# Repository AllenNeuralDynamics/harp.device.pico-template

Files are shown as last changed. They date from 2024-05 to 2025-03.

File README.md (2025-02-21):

# harp.device.pico-template

An RP2040-based Harp hardware/firmware project template.

## Features
* predefined *.gitignore* file to remove extraneous KiCAD (hardware) files.
### Hardware
* Schematic template for a generic Harp Device including:
  * ground-isolated Full Speed USB communication
  * 3.5mm audio jack for Harp-protocol time synchronization
  * RP2040 MCU and required "jellybean" components including:
    * 2MB external flash (Winbond MPN: W25Q16JVUXIQ TR).
  * 2 power supply chain options for power derived from either USB directly or from a DC barrel jack.
* Basic PCBA Layout with size hints for various existing enclosures
  * DC Barrel Jack (2.1 x 5.5mm, positive center)
  * USBC
  * 3.5mm audio jack for Harp synchronization signal
  * Ground lug
### Firmware
* basic "hello-world" project with corresponding file structure
* populated CMakeLists.txt for compliation
* placeholder USB descriptors for Manufacturer and Description fields (in the CMakeLists.txt)
* compilation [instructions](./firmware/README.md)
* harp protocol core library included as a submodule [harp.core.pico](https://github.com/AllenNeuralDynamics/harp.core.pico)

# Using this template
Start by clicking the "Use this Template" button in the upper right corner, or click [here](https://github.com/new?template_name=harp.device.pico-template&template_owner=AllenNeuralDynamics).
## Repository Setup
* If the project has a corresponding Allen Institute SIPE project number, prepend the repository description with: `{SIPE Project Number}:`.
* add the tag `Harp`
* Long-term: remove these instructions!

## Hardware
* Remove all unused hardware folder starter projects.
* 🔧 Design your hardware.
* In the PCBA silkscreen, add:
  * SIPE part number with full hardware semantic version appended in the format: `{SIPE Project Number}-E-{hw major}-{hw minor}-{hw patch}`. Version number fields range from 1-999 and include leading zeros.
  * [QR code](https://www.the-qrcode-generator.com/) linking to the Github repository.

## Firmware
* Update the *Manufacturer* and *Description* USB descriptors in the CMakeLists.txt
* 📝 Write your firmware.

# Github Release Conventions
Releases specify any vetted changes to the hardware or firmware.

Each release specifies:
* semantic versions of changed elements: hardware or firmware.
* SIPE part number (or part numbers if multiple are compatible)

Each hardware release includes:
* STEP file of the PCB (or link to corresponding CAD files) named with the SIPE part number
* schematic (PDF)
* Gerber files (with logos removed) of the PCBA
* Position files for component placement
* Bill-of-Materials for the PCBA

Each hardware release specifies:
* compatible SIPE part number(s)

> [!NOTE]
> SIPE part numbers only encode hardware semantic version major number, so multiple minor/patch hardware releases may point to the same SIPE part number.

> [!NOTE]
> It is possible for a project to have PCBA variants--possibly with very different functionality. In this case, reserve a hardware major version range (>100 suggested) for this variant and treat it as a distinct hardware release (i.e: with all corresponding included hardware files).

Each firmware release specifies:
* firmware semantic version
* compatible hardware (SIPE part number or part number range).

Each firmware release includes:
* compiled binary file (**\*.uf2**) of the firmware.

## Release Title
The release title is specified as follows:

`hw{hw major}.{hw minor}.{hw patch}-fw{fw major}.{fw minor}.{fw patch}`

If the release has firmware-only changes, you can drop the `hw*` section, and vice versa.

> [!NOTE]
> After Oct 2024, hardware major fields on all future releases will be equivalent to the major version number of the SIPE part number. See the [SIPE PCBA part numbering standard](https://alleninstitute.sharepoint.com/:w:/s/Instrumentation/EYsRN8q4jHJDmG5DNf-gaM0Bq418YMXollFxtB9d_NZ6pg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) for more details.

The above field spec enables automation utilities to find the latest firmware version and automatically update compatible hardware. Since releases can include changes to some, but not other fields, unchanged fields are omitted. (i.e: firmware-only changes would be titled `fw{fw major}.{fw minor}.{fw patch}`.)

## Creating a New Release
1. Make a [git tag](https://git-scm.com/book/en/v2/Git-Basics-Tagging) based on the commit in the main branch that you'd like to create the release from. Use the naming convention specified in the [Release Title](#release-title) section.
2. Push the tag to Github.
3. From the repository's corresponding *Release* page, create a new release from the tag you just added. Give it the same title as the tag.
4. If the release includes new _firmware_, compile it locally, and upload a copy of the *.uf2* file as an attachment.
5. If the release includes new _hardware_, upload:
    1. the gerber files (zipped)
    2. the position files
    3. any manufacturing notes (component orientations)
    4. the bill-of-materials
    5. a PDF of the schematic.

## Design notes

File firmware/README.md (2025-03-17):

There are two sets of instructions, one for [Windows](#windows-setup) and one for [Linux](linux-setup).

# Windows Setup

Windows has two sub-options for developing:
* Option A: use Visual Studio Code (easy way)
* Option B: develop with any IDE and compile from the command line.

> [!NOTE]
> For Option B, simply install [Windows Subsystem for Linux](https://learn.microsoft.com/en-us/windows/wsl/install), and then follow the directions in the [Linux](#linux-setup) section of this guide. The rest of this section covers Option A.
  
## Pre-requisites
1. Install [Visual Studio Code](https://code.visualstudio.com/).
2. Install the [Pico Extension for Visual Studio Code](https://marketplace.visualstudio.com/items?itemName=raspberry-pi.raspberry-pi-pico)

## Project Setup
In Visual Studio, click on the Pico icon that appears after installing the Pico Extension. Select _Import Project_ and import the _firmware_ folder of this repository.
Choose the default options.

## Compiling the Firmware
Click the _compile_ button at the corner of the screen. When the compilation finishes, you're ready to [flash the firmware](#flashing-the-firmware).

# Linux Setup

## Pre-requisites

You will need CMake, make, and the gcc-arm-embedded toolchain.

On Linux, install the following:
```bash
sudo apt install cmake python3 build-essential gcc-arm-none-eabi libnewlib-arm-none-eabi libstdc++-arm-none-eabi-newlib
```

### Install Submodules
This project uses the Harp [core.pico](https://github.com/harp-tech/core.pico) library as a submodule.
Install it with:
````
git submodule update --init
````

### Install Pico SDK
This project uses the [Pico SDK](https://github.com/raspberrypi/pico-sdk/tree/master).
The SDK needs to be downloaded and installed to a known folder on your PC.
Note that the PICO SDK also contains submodules (including TinyUSB), so you must ensure that they are also fetched with:
````
git clone git clone git@github.com:raspberrypi/pico-sdk.git
git submodule update --init --recursive
````

### Point to Pico SDK
Optional: define the `PICO_SDK_PATH` environment variable to point to the location where the pico-sdk was downloaded. i.e:
````
PICO_SDK_PATH=/home/username/projects/pico-sdk
````
On Linux, you can define it in your `.bashrc` file.
On Windows, you can define it via System Properties ([tutorial](https://www.computerhope.com/issues/ch000549.htm)).

Confirm that the environment variable is applied to your system by opening a terminal (Powershell on Windows) and
entering (with the `$` sign)
```bash
$PICO_SDK_PATH
```
to confirm that the path was defined correctly.
(Windows may require a restart for the environment variable to take effect.)

## Compiling the Firmware

### With the Visual Studio Code Extension
Using the Pico extension, import the *firmware* folder with the default options.

Click the compile button.

### Without an IDE
From within this folder, create a new folder called *build*, enter it, and invoke cmake with:
````
mkdir build
cd build
cmake ..
````
If you did not define the `PICO_SDK_PATH` as an environment variable, you must pass it in here like so:
````
mkdir build
cd build
cmake -DPICO_SDK_PATH=/path/to/pico-sdk ..
````
After this point, you can invoke the auto-generated Makefile with `make`

## Flashing the Firmware
Press-and-hold the Pico's BOOTSEL button and power it up (i.e: plug it into usb).
At this point you do one of the following:
* drag-and-drop the created **\*.uf2** file into the mass storage device that appears on your pc.
* flash with [picotool](https://github.com/raspberrypi/picotool)

# References
* [YouTube: How to Set Up Visual Studio Code to Program the Pi Pico (Windows)](https://www.youtube.com/watch?v=mUF9xjDtFfY&t=55s)
* [Pico SDK: Unix Command Line](https://github.com/raspberrypi/pico-sdk?tab=readme-ov-file#unix-command-line) Setup

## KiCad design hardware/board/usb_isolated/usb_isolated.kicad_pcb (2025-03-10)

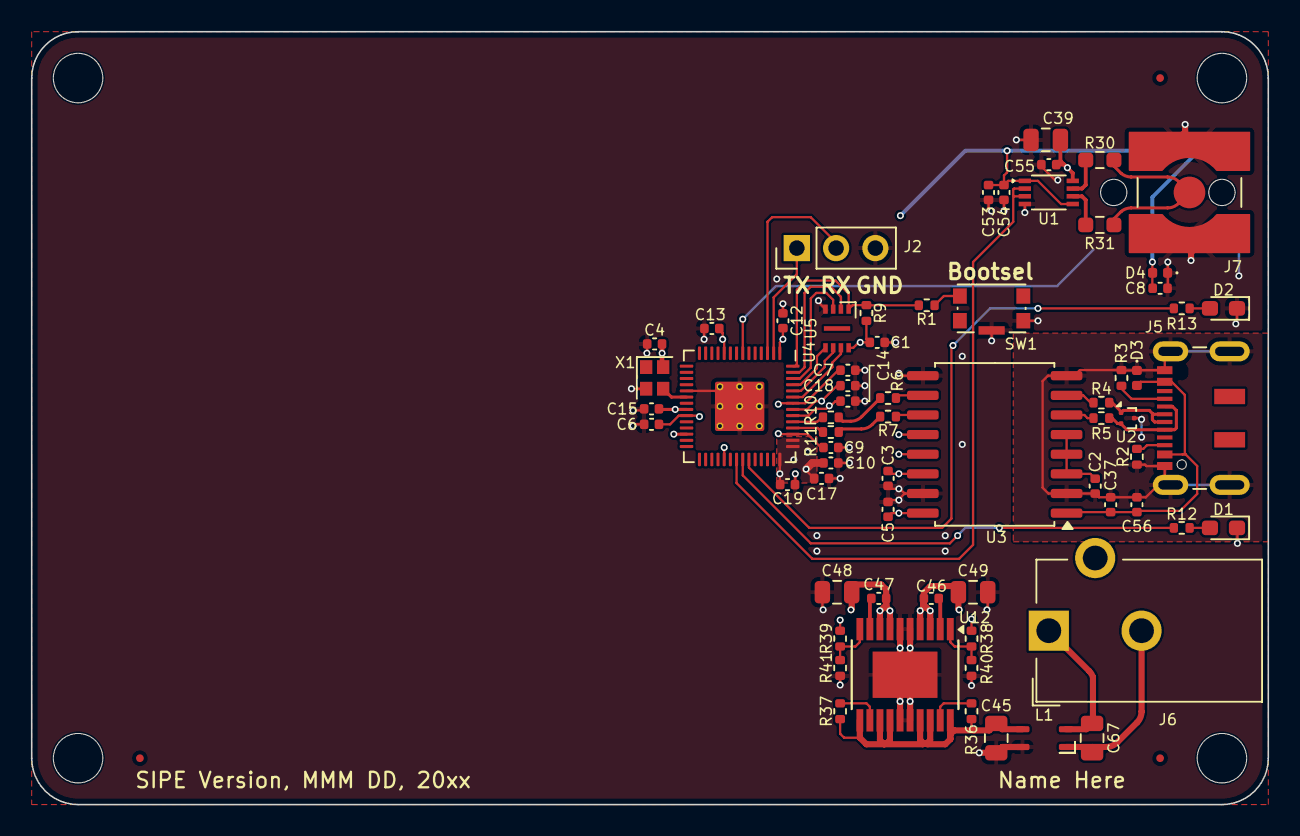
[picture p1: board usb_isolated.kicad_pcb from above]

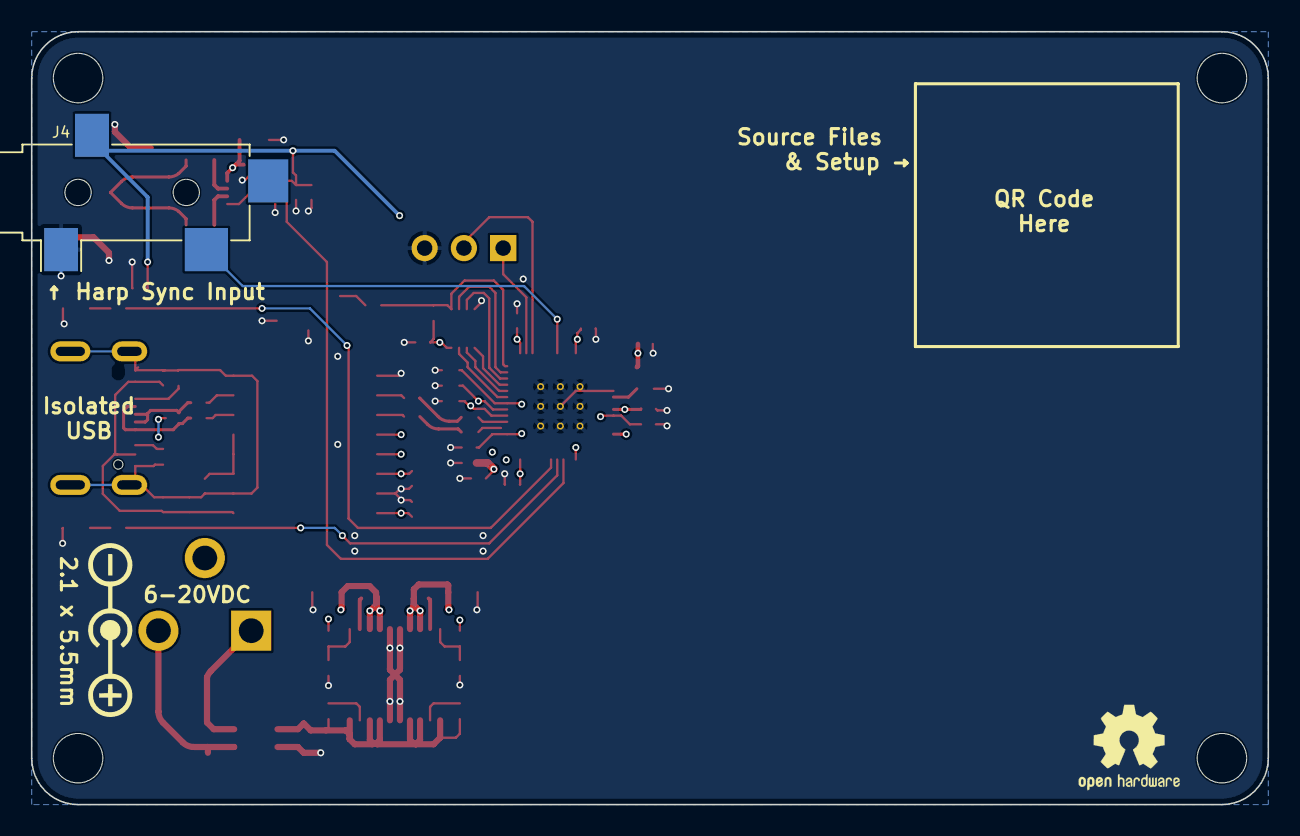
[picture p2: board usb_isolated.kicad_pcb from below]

Board: 4 copper layers, 80.0 x 50.0 mm, 72 parts (3 on the bottom side), 47 nets.

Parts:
C1, C2, C3, C5, C6, C7, C12, C13, C14, C15, C17, C18, C19, C37, C54, C55: 100nF; C_0402_1005Metric
C4, C46, C47: 10nF; C_0402_1005Metric
C8, C9, C10, C53, C56: 1uF; C_0402_1005Metric
C39, C48: 10uF; C_0805_2012Metric
C45, C67: 3.3uF; C_0805_2012Metric
C49: 22uF; C_0805_2012Metric
D1, D2: LED; LED_0603_1608Metric_Pad1.05x0.95mm_HandSolder
D3, D4: D_TVS; D_0402_1005Metric
FID1, FID2, FID3: Fiducial; Fiducial_0.5mm_Mask1mm
G3: LOGO
J2: Conn_01x03_Male; PinHeader_1x03_P2.54mm_Vertical
J4: AudioJack3; Jack_3.5mm_CUI_SJ-3524-SMT_Horizontal
J5: USB_C_Receptacle_USB2.0; USB_C_Receptacle_JAE_DX07S016JA1R1500
J6: Barrel_Jack_Switch; BarrelJack_CUI_PJ-102AH_Horizontal
J7: Conn_Coaxial; SMA_TE_Connectivity_CONSMA002-SMD-G-T_Horizontal
L1: L_Coupled_1423; L_CommonModeChoke_TDKCorporation_1210
R1: 1K; R_0402_1005Metric
R2, R3: 5K1; R_0402_1005Metric
R4, R5, R6, R7: 24; R_0402_1005Metric
R9: 10K; R_0402_1005Metric
R10, R11: 27; R_0402_1005Metric
R12, R13: 680; R_0402_1005Metric
R30, R31: 100; R_0603_1608Metric_Pad0.98x0.95mm_HandSolder
R36, R37: 1M; R_0402_1005Metric
R38: 309K; R_0402_1005Metric
R39: 172K; R_0402_1005Metric
R40, R41: 100K; R_0402_1005Metric
REF1: OSHW-Logo2_7.3x6mm_SilkScreen
SW1: SW_Push_1P1T-SH_NO_Vertical_Wuerth_WS-TASV
U1: 74LVCH2T45DC; VSSOP-8_2.3x2mm_P0.5mm
U2: TPD2EUSB30; Texas_DRT-3
U3: ADUM4160; SOIC-16W_7.5x10.3mm_P1.27mm
U4: RP2040; RP2040-QFN-56
U5: W25Q16JVUXIQ; Winbond-8USON-2x3mm
U12: LT3030; ETSSOP-20-1EP_4.4x6.5mm_P0.65mm_EP3x4.2mm
X1: ECS-TXO-2016; Crystal_SMD_2016-4Pin_2.0x1.6mm

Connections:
+1V1: C6.2, C7.2, C9.1, U4.23 (DVDD), U4.45 (VREG_VOUT), U4.50 (DVDD)
+3.3V: C1.2, C3.2, C4.2, C5.2, C8.1, C10.1, C12.2, C13.2, C14.2, C15.2, C17.2, C18.2, C19.2, C47.1, C48.1, C53.1, C54.2, D4.2 (A2), J4.R, R9.2, R39.1, U1.1 (VCCA), U1.5 (DIR), U3.12 (PIN), U3.13 (SPD), U3.14 (VDD2), U3.16 (VBUS2), U4.1 (IOVDD), U4.10 (IOVDD), U4.22 (IOVDD), U4.26 (RUN), U4.33 (IOVDD), U4.42 (IOVDD), U4.43 (ADC_AVDD), U4.44 (VREG_IN), U4.48 (USB_VDD), U4.49 (IOVDD), U5.8 (VCC), U12.7 (OUT2), U12.8 (OUT2), X1.4 (VDD)
+5V: C39.1, C46.1, C49.1, C55.2, R38.1, U1.8 (VCCB), U12.3 (OUT1), U12.4 (OUT1)
+12V: C67.1, J6.1, L1.2
/Harp Core RP2040 + Isolated USB/D+: J5.A6 (D+), J5.B6 (D+), R4.1, U2.1 (D+)
/Harp Core RP2040 + Isolated USB/D-: J5.A7 (D-), J5.B7 (D-), R5.1, U2.2 (D-)
/Harp Core RP2040 + Isolated USB/DD+: R6.2, R10.2
/Harp Core RP2040 + Isolated USB/DD-: R7.2, R11.2
/Harp Core RP2040 + Isolated USB/HARP_CLK_SYNC: J4.T, U4.7 (GPIO5)
/Harp Core RP2040 + Isolated USB/QSPI_CLK: U4.52 (QSPI_SCLK), U5.6 (CLK)
/Harp Core RP2040 + Isolated USB/QSPI_CS: R1.2, R9.1, U4.56 (QSPI_SS), U5.1 (~CS)
/Harp Core RP2040 + Isolated USB/QSPI_D0: U4.53 (QSPI_SD0), U5.5 (DI(IO0))
/Harp Core RP2040 + Isolated USB/QSPI_D1: U4.55 (QSPI_SD1), U5.2 (DO(IO1))
/Harp Core RP2040 + Isolated USB/QSPI_D2: U4.54 (QSPI_SD2), U5.3 (IO2)
/Harp Core RP2040 + Isolated USB/QSPI_D3: U4.51 (QSPI_SD3), U5.7 (IO3)
/Harp Core RP2040 + Isolated USB/TTL_OUT: U1.2 (1A), U1.3 (2A), U4.35 (GPIO23)
/Harp Core RP2040 + Isolated USB/UART0_RXD: J2.2, U4.3 (GPIO1)
/Harp Core RP2040 + Isolated USB/UART0_TXD: J2.1, U4.2 (GPIO0)
/Harp Core RP2040 + Isolated USB/USB_Boot: R1.1, SW1.2
/Harp Core RP2040 + Isolated USB/VDD1: C2.2, U3.3 (VDD1), U3.4 (PDEN), U3.5 (SPU)
GND: C1.1, C3.1, C4.1, C5.1, C6.1, C7.1, C8.2, C9.2, C10.2, C12.1, C13.1, C14.1, C15.1, C17.1, C18.1, C19.1, C39.2, C45.2, C48.2, C49.2, C53.2, C54.1, C55.1, D1.1 (K), D2.1 (K), D4.1 (A1), J2.3, J4.S, J7.2 (Ext), L1.4, R40.1, R41.1, SW1.4, SW1.SH, U1.4 (GND), U3.9 (GND2), U3.15 (GND2), U4.19 (TESTEN), U4.57 (GND), U5.4 (GND), U12.5 (GND), U12.6 (GND), U12.15 (GND), U12.16 (GND), U12.21 (GND), X1.2 (GND)
GND1: C2.1, C37.1, C56.2, D3.1 (A1), J5.A1 (GND), J5.A12 (GND), J5.B1 (GND), J5.B12 (GND), J5.S1 (SHIELD), R2.2, R3.2, U2.3 (GND), U3.2 (GND1), U3.8 (GND1)
GND2: C67.2, J6.2, L1.1
IN1: C45.1, L1.3, R36.1, R37.1, U12.11 (~SHDN2), U12.13 (IN2), U12.14 (IN2), U12.17 (IN1), U12.18 (IN1), U12.20 (~SHDN1)
unnamed: D1.2 (A), R12.2
unnamed: D2.2 (A), R13.2
unnamed: J5.A5 (CC1), R2.1
unnamed: J5.B5 (CC2), R3.1
unnamed: J7.1 (In), R30.2, R31.2
unnamed: R30.1, U1.7 (1B)
unnamed: R31.1, U1.6 (2B)
unnamed: R6.1, U3.10 (DD+)
unnamed: R7.1, U3.11 (DD-)
unnamed: R4.2, U3.7 (UD+)
unnamed: R5.2, U3.6 (UD-)
unnamed: R12.1, U4.36 (GPIO24)
unnamed: R13.1, U4.37 (GPIO25)
unnamed: R11.1, U4.46 (USB_DM)
unnamed: R10.1, U4.47 (USB_DP)
unnamed: U4.20 (XIN), X1.3 (OUT)
unnamed: R38.2, R40.2, U12.1 (ADJ1)
unnamed: R39.2, R41.2, U12.10 (ADJ2)
unnamed: C46.2, U12.2 (BYP1)
unnamed: C47.2, U12.9 (BYP2)
unnamed: R36.2, U12.19 (PWRGD1)
unnamed: R37.2, U12.12 (PWRGD2)
VBUS: C37.2, C56.1, D3.2 (A2), J5.A4 (VBUS), J5.A9 (VBUS), J5.B4 (VBUS), J5.B9 (VBUS), U3.1 (VBUS1)

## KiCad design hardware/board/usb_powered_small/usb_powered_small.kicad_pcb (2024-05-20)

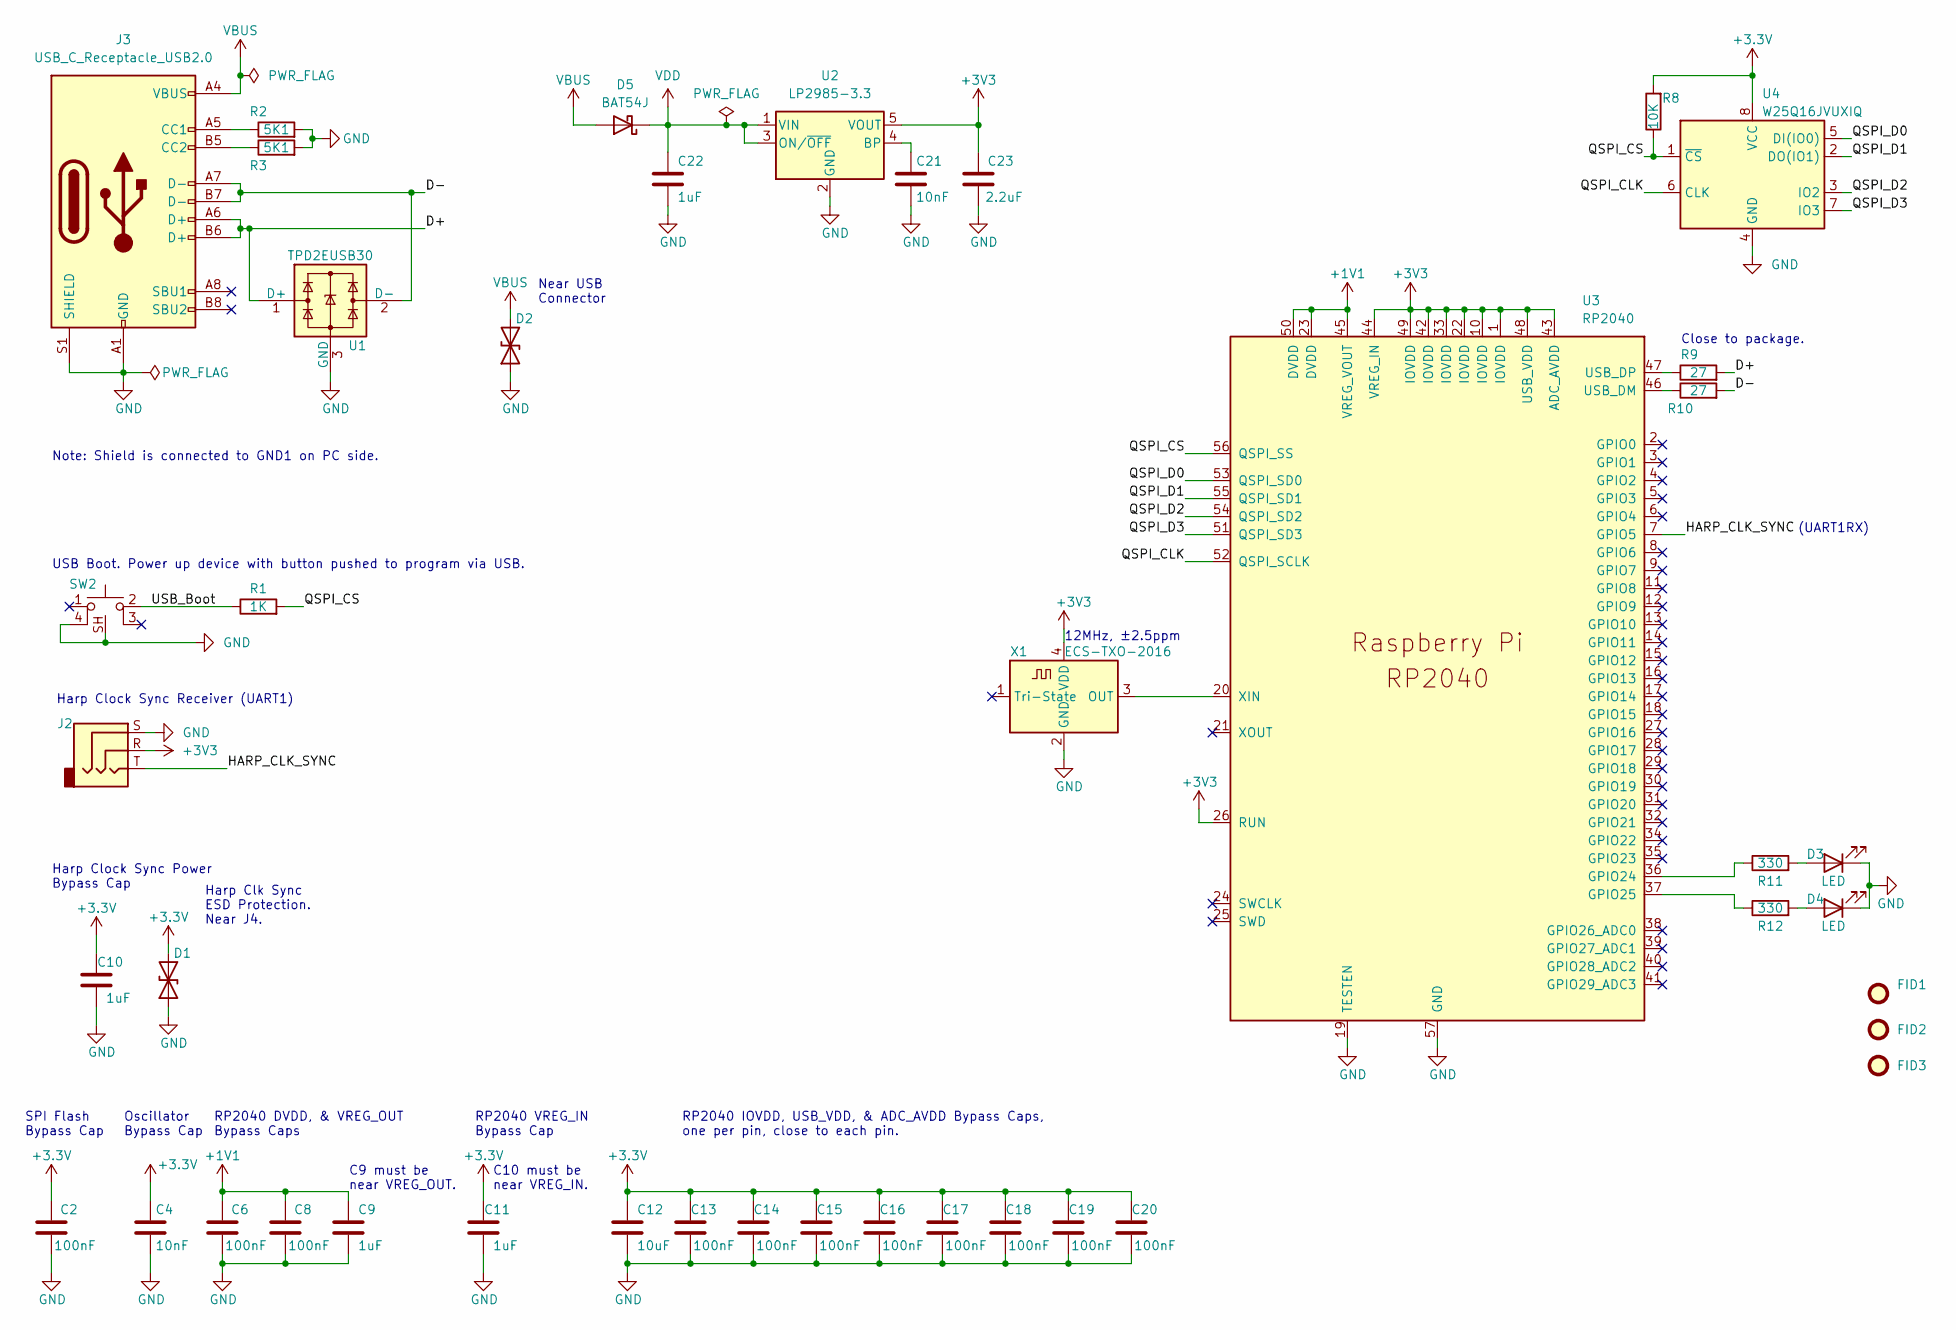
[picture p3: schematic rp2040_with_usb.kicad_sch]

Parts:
C2, C6, C8, C13, C14, C15, C16, C17, C18, C19, C20: 100nF; C_0402_1005Metric; Rated Voltage 16V; Tolerance 10%
C4, C21: 10nF; C_0402_1005Metric; Rated Voltage 25V; Tolerance 2%
C9, C10, C11, C22: 1uF; C_0402_1005Metric; Rated Voltage 35V
C12: 10uF; C_0805_2012Metric; Rated Voltage 25V
C23: 2.2uF; C_0402_1005Metric; Rated Voltage 10V
D1, D2: D_TVS; D_0402_1005Metric
D3, D4: LED; LED_0603_1608Metric_Pad1.05x0.95mm_HandSolder
D5: BAT54J; D_SOD-323F
FID1, FID2, FID3: Fiducial; Fiducial_0.5mm_Mask1mm
J2: AudioJack3; Jack_3.5mm_CUI_SJ-3523-SMT_Horizontal
J3: USB_C_Receptacle_USB2.0; USB_C_Receptacle_JAE_DX07S016JA1R1500
R1: 1K; R_0402_1005Metric; Tolerance 1%
R2, R3: 5K1; R_0402_1005Metric; Tolerance 1%
R8: 10K; R_0402_1005Metric; Tolerance 1%
R9, R10: 27; R_0402_1005Metric; Tolerance 1%
R11, R12: 330; R_0402_1005Metric; Tolerance 0.1%
SW2: SW_Push_1P1T-SH_NO_Vertical_Wuerth_WS-TASV
U1: TPD2EUSB30; Texas_DRT-3
U2: LP2985-3.3; SOT-23-5
U3: RP2040; RP2040-QFN-56
U4: W25Q16JVUXIQ; Winbond-8USON-2x3mm
X1: ECS-TXO-2016; Crystal_SMD_2016-4Pin_2.0x1.6mm; Tolerance ±2.5ppm

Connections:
+1V1: C6.2, C8.2, C9.1, U3.23 (DVDD), U3.45 (VREG_VOUT), U3.50 (DVDD)
/Harp Core RP2040 + USB/D+: J3.A6 (D+), J3.B6 (D+), R9.2, U1.1 (D+)
/Harp Core RP2040 + USB/D-: J3.A7 (D-), J3.B7 (D-), R10.2, U1.2 (D-)
/Harp Core RP2040 + USB/HARP_CLK_SYNC: J2.T, U3.7 (GPIO5)
/Harp Core RP2040 + USB/QSPI_CLK: U3.52 (QSPI_SCLK), U4.6 (CLK)
/Harp Core RP2040 + USB/QSPI_CS: R1.2, R8.1, U3.56 (QSPI_SS), U4.1 (~CS)
/Harp Core RP2040 + USB/QSPI_D0: U3.53 (QSPI_SD0), U4.5 (DI(IO0))
/Harp Core RP2040 + USB/QSPI_D1: U3.55 (QSPI_SD1), U4.2 (DO(IO1))
/Harp Core RP2040 + USB/QSPI_D2: U3.54 (QSPI_SD2), U4.3 (IO2)
/Harp Core RP2040 + USB/QSPI_D3: U3.51 (QSPI_SD3), U4.7 (IO3)
/Harp Core RP2040 + USB/USB_Boot: R1.1, SW2.2
GND: C2.1, C4.2, C6.1, C8.1, C9.2, C10.2, C11.2, C12.2, C13.1, C14.1, C15.1, C16.1, C17.1, C18.1, C19.1, C20.1, C21.2, C22.2, C23.1, D1.1 (A1), D2.1 (A1), D3.1 (K), D4.1 (K), J2.S, J3.A1 (GND), J3.A12 (GND), J3.B1 (GND), J3.B12 (GND), J3.S1 (SHIELD), R2.2, R3.2, SW2.4, SW2.SH, U1.3 (GND), U2.2 (GND), U3.19 (TESTEN), U3.57 (GND), U4.4 (GND), X1.2 (GND)
unnamed: D3.2 (A), R11.2
unnamed: D4.2 (A), R12.2
unnamed: J3.A5 (CC1), R2.1
unnamed: J3.B5 (CC2), R3.1
unnamed: C21.1, U2.4 (BP)
unnamed: R11.1, U3.36 (GPIO24)
unnamed: R12.1, U3.37 (GPIO25)
unnamed: R10.1, U3.46 (USB_DM)
unnamed: R9.1, U3.47 (USB_DP)
unnamed: U3.20 (XIN), X1.3 (OUT)
VBUS: D2.2 (A2), D5.2 (A), J3.A4 (VBUS), J3.A9 (VBUS), J3.B4 (VBUS), J3.B9 (VBUS)
VDD: C22.1, D5.1 (K), U2.1 (VIN), U2.3 (ON/~OFF)

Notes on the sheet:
C10 must be near VREG_IN.
C9 must be near VREG_OUT.
SPI Flash Bypass Cap
Close to package.
Harp Clock Sync Power Bypass Cap
Harp Clock Sync Receiver (UART1)
Oscillator Bypass Cap
RP2040 DVDD, & VREG_OUT Bypass Caps
RP2040 VREG_IN Bypass Cap
USB Boot. Power up device with button pushed to program via USB.
(UART1RX)
RP2040 IOVDD, USB_VDD, & ADC_AVDD Bypass Caps, one per pin, close to each pin.
Near USB Connector
Note: Shield is connected to GND1 on PC side.
12MHz, ±2.5ppm
Harp Clk Sync ESD Protection. Near J4.

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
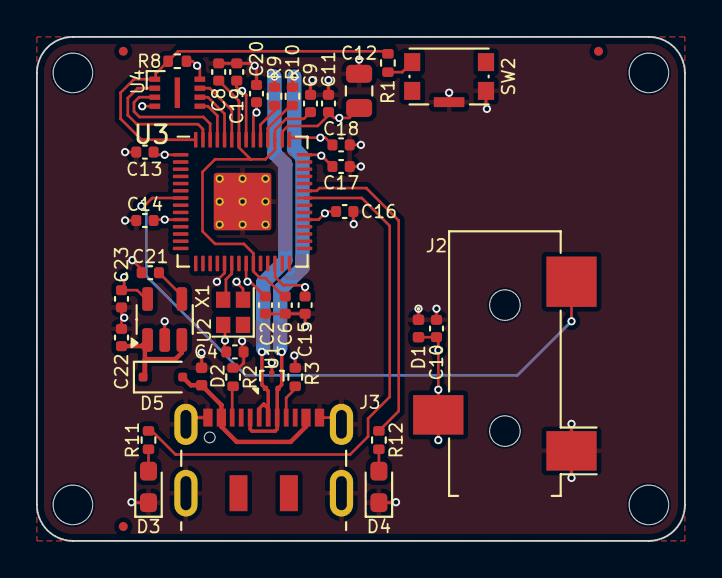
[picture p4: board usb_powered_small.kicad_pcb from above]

Board: 4 copper layers, 36.0 x 28.0 mm, 43 parts (0 on the bottom side), 25 nets.

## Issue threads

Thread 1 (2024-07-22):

Add short commit id to project name as a suffix

Poofjunior, 2024-07-22:
The project template should be in the format <project_name>-<COMMIT_ID> so that binary *.uf2 files have some level of traceability.

Here's a command from CMake that should work as long as `git` is installed.
https://stackoverflow.com/questions/71762846/set-cmake-project-description-with-commit-id

Poofjunior, 2024-07-24:
pushed to main.

Closed 2024-07-24.

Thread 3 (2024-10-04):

Update audio jack to use version with more alternates

Poofjunior, 2024-10-04:
Currently, we use the audio jack PN: SJ-3523-SMT-TR-GR, which is regularly out of stock.

We should switch to SJ-3524-SMT-TR-GR, which has multiple color variants, making it more likely we can mint boards faster with one of the alternates if the main part is out of stock.

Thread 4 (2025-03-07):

Cleanup KiCAD PCBA Layout

Poofjunior, 2025-03-07:
The template PCBA layout is directly pasted from the [lickety-split](https://github.com/AllenNeuralDynamics/harp.device.lickety-split) repo and needs to be simplified to be more useful as a starting point.

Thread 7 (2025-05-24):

Change TVS Diode?

cjsha, 2025-05-24:
These TVS diodes are supposed to protect the 3.3V at the HARP Aux port.

- D1 in rp2040_with_usb
- D4 in isolated_usb_rp2040

The linked datasheets for the diodes indicate the standoff voltage is 5.3V, but they should be close to 3.3V? I'm not sure they're the actual TVS diodes you end up using though, their Value field doesn't have a MPN. Also, the datasheet linked for TVS diodes in the schematic is for discontinued TVS diodes, another reason to believe you don't actually use the TVS diodes from the datasheet in the KiCAD symbol. It's not too much of an issue, but thought I'd mention it anyway just in case

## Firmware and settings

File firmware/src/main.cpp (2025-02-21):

#include <cstring>
#include <harp_c_app.h>
#include <harp_synchronizer.h>
#include <core_registers.h>
#include <reg_types.h>
#include <config.h>
#ifdef DEBUG
    #include <pico/stdlib.h> // for uart printing
    #include <cstdio> // for printf
#endif


// Create device name array.
const uint16_t who_am_i = 1234;
const uint8_t hw_version_major = 0;
const uint8_t hw_version_minor = 0;
const uint8_t assembly_version = 0;
const uint8_t harp_version_major = 0;
const uint8_t harp_version_minor = 0;
const uint8_t fw_version_major = 0;
const uint8_t fw_version_minor = 0;
const uint16_t serial_number = 0xCAFE;

// Harp App Register Setup.
const size_t reg_count = 2;

// Define register contents.
#pragma pack(push, 1)
struct app_regs_t
{
    volatile uint8_t test_byte;  // app register 0
    volatile uint32_t test_uint; // app register 1
} app_regs;
#pragma pack(pop)

// Define register "specs."
RegSpecs app_reg_specs[reg_count]
{
    {(uint8_t*)&app_regs.test_byte, sizeof(app_regs.test_byte), U8},
    {(uint8_t*)&app_regs.test_uint, sizeof(app_regs.test_uint), U32}
};

// Define register read-and-write handler functions.
RegFnPair reg_handler_fns[reg_count]
{
    {&HarpCore::read_reg_generic, &HarpCore::write_reg_generic},
    {&HarpCore::read_reg_generic, &HarpCore::write_to_read_only_reg_error}
};

void app_reset()
{
    app_regs.test_byte = 0;
    app_regs.test_uint = 0;
}

void update_app_state()
{
    // update here!
    // If app registers update their states outside the read/write handler
    // functions, update them here.
    // (Called inside run() function.)
}

// Create Harp App.
HarpCApp& app = HarpCApp::init(HARP_DEVICE_ID,
                               HW_VERSION_MAJOR, HW_VERSION_MINOR,
                               HW_ASSEMBLY_VERSION,
                               HARP_VERSION_MAJOR, HARP_VERSION_MINOR,
                               FW_VERSION_MAJOR, FW_VERSION_MINOR,
                               UNUSED_SERIAL_NUMBER, "widget",
                               (uint8_t*)GIT_HASH,
                               &app_regs, app_reg_specs,
                               reg_handler_fns, reg_count, update_app_state,
                               app_reset);

// Core0 main.
int main()
{
// Init Synchronizer.
    HarpSynchronizer::init(uart1, HARP_SYNC_RX_PIN);
    app.set_synchronizer(&HarpSynchronizer::instance());
#ifdef DEBUG
    stdio_uart_init_full(uart0, 921600, UART_TX_PIN, -1); // use uart1 tx only.
    printf("Hello, from an RP2040!\r\n");
#endif
    while(true)
        app.run();
}

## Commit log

2024-05-20 add pcb starting points
    [board_power.kicad_sch, isolated_usb_rp2040.kicad_sch, rp2040_with_usb.kicad_sch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]
2025-02-19 update how pico sdk path is searched for
2025-02-21 cleanup template config, add git hash, update pico core
2025-03-10 update usb isolated pcba layout
    [board_power.kicad_sch, isolated_usb_rp2040.kicad_sch, sma_ttl_out.kicad_sch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]
2025-04-29 update remote url for pico core
